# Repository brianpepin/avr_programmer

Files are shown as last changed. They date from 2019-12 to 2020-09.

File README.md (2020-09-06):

# AVR Programmer
Eagle files and gerbers for a programmer designed for Microchip's series of AVR microcontrollers. There is also a KiCad variant in the kicad directory, but I haven't tried it yet.  It was ported from Eagle and I re-routed the board.

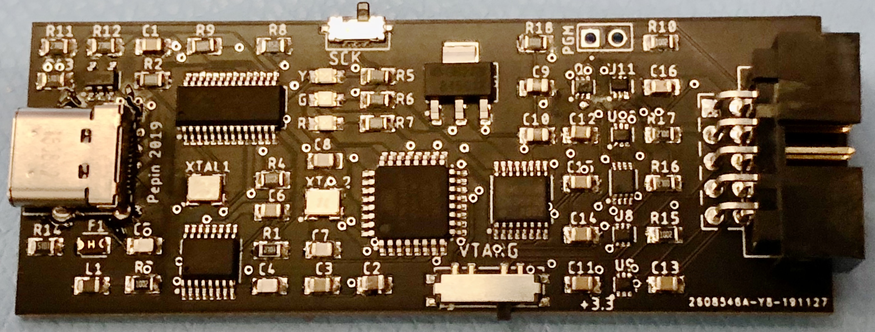
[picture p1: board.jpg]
Board Image


## Overview
Microchip's series of AVR chips are simple 8 bit microcontrollers often used in Arduino boards. This programmer board can be used to program fuses and flash for bare AVR chips.

## Features

* Compatible with USBASP firmware and features, including slow clock.
* Selectable target voltage of 3.3v, 5v, or target provided (1.8v - 5.5v).
* Built-in serial to USB converter.
* Board can remain connected to target after programming.
* USB-C interface to PC with full ESD and overload protection.

## Design

This board is based on the hardware design for [USBASP](https://www.fischl.de/usbasp/) and is 100% compatible wth the USBASP firmware. I designed it to support different target voltages (namely 3.3v) and wanted built-in serial IO so I could connect a single connector to boards I design.

The board shows up as two USB devices: a FTDI serial port and a USBASP programmer.  There is an on-board USB hub that exposes both devices.  Target voltage is selectable through the VTARG switch and has three values:

1. 5V (left): Provide 5 volts as power and logic levels to the target board.
1. Float (middle): Adapt to whatever voltage the target board is using.
1. 3.3V (right): Provide 3.3 volts as power and logic levels to the target board.

If your board provides voltage of its own make sure you keep VTARG in the middle position.

The different voltage levels are shifted through an array of level shifters.  This circuit will change direction of the signals if PGM is bridged, which allows for initial programming of the board. All connections other than TXD and RXD also go to a high-impedance state whenever the red programming light is off (I reuse that signal line so I don't need any modifications to the USBASP firmware). Signal direction and tri-state is controlled by discrete logic, again so no USBASP mods are needed.  The level shifters I'm using go to high-impedance state when VCCA or VCCB is grounded.  This is handled by a push-pull pair of mosfets driven by discrete logic.

## Programming

Once the board is complete it must be flashed with the USBASP code. You need another working programmer for this.

1. Bridge the PGM pins on the board and set VTARG to either 5v or 3.3v depending on the output voltage of your existing programmer.
1. Connect your existing programmer's connector to the board.
1. Set your programmer to use a slow clock.
1. Run 'make Makefile88 fuses' from the USBASP project.
1. You can now turn off the slow clock feature of your programmer.
1. Run 'make Makefile88" to flash the firmware.

If successful, a green LED should be lit on the board. This LED is controlled by the USBASP firmware so it's a good indicator everything's working.  Remove the bridge to PGM and you should be good to go.

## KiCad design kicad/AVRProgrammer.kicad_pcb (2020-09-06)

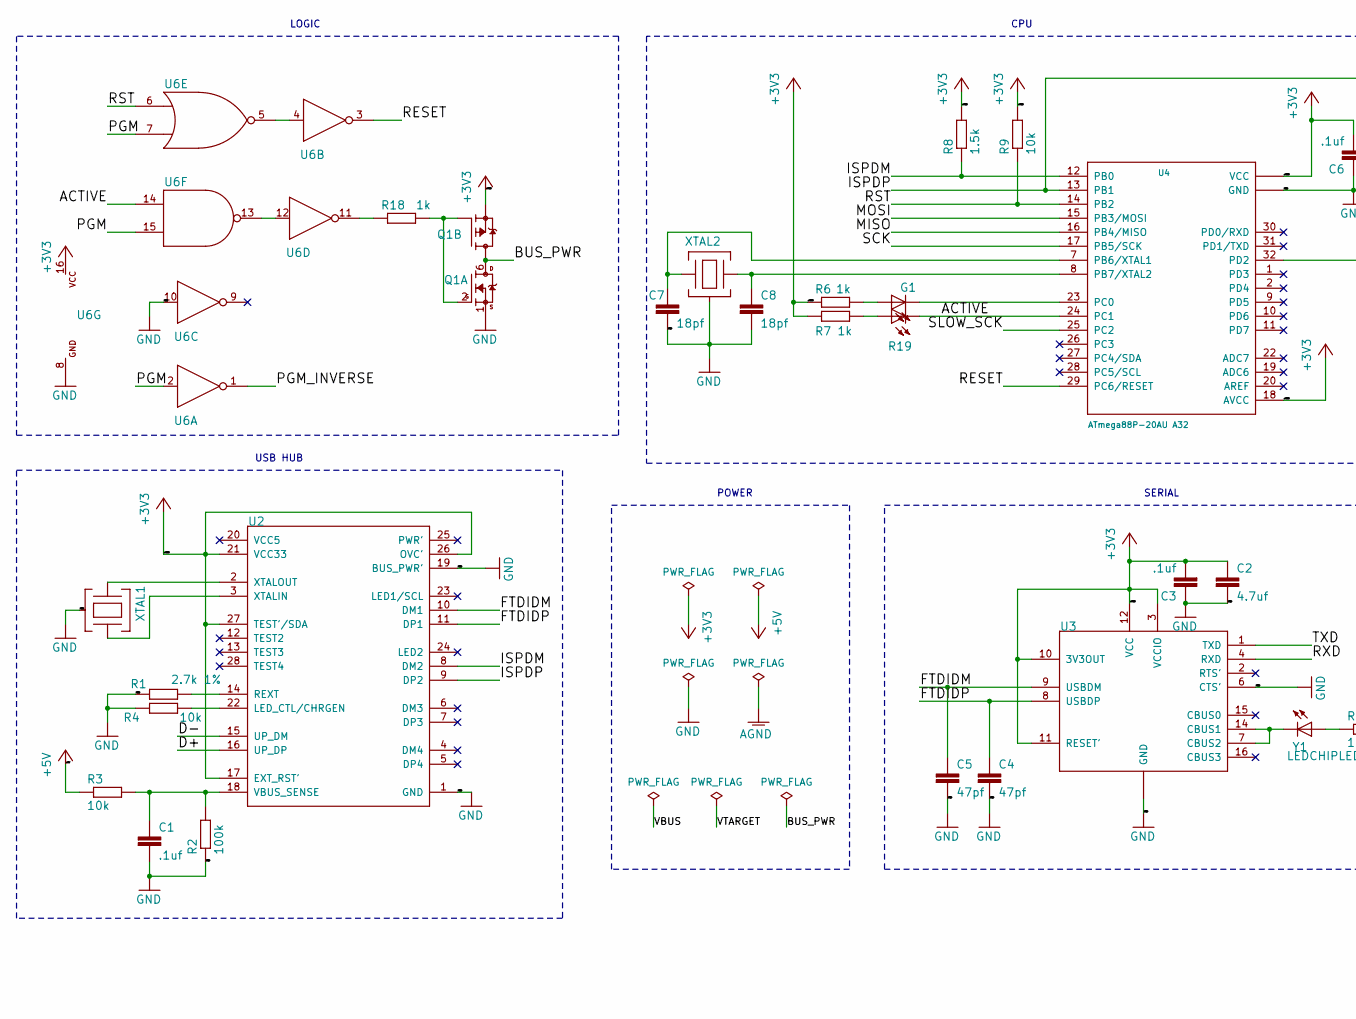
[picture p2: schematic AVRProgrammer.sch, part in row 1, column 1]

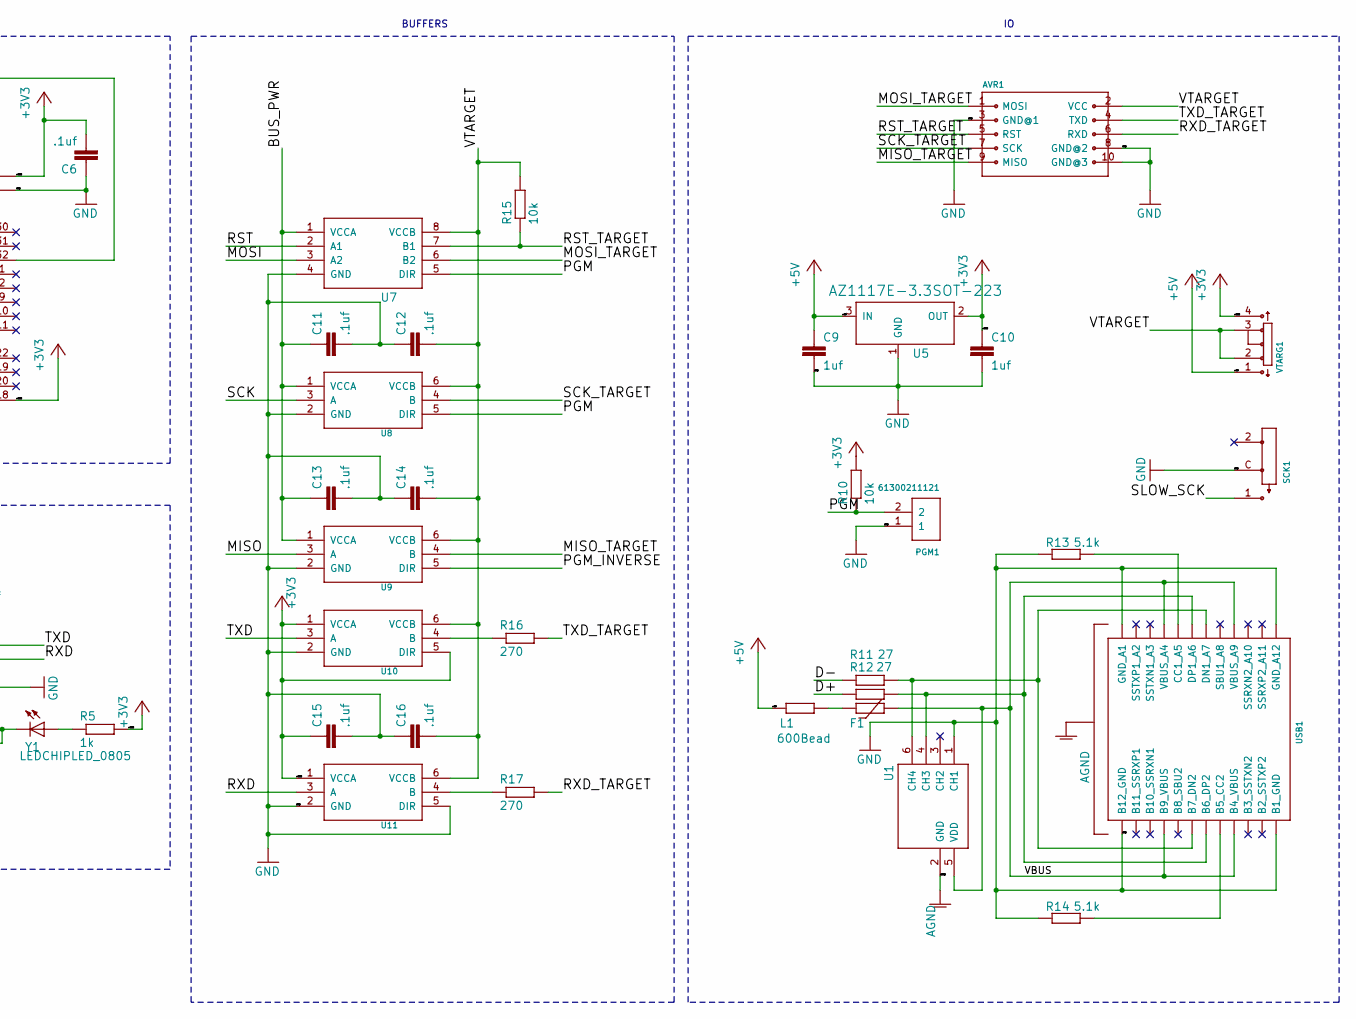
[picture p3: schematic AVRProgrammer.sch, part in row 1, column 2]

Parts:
AVR1: 10PIN_ISP10PIN_ISP_RT; 10PIN_ISP_RT
C1, C3, C6, C11, C12, C13, C14, C15, C16: .1uf; C0805
C2: 4.7uf; C0805
C4, C5: 47pf; C0805
C7, C8: 18pf; C0805
C9, C10: 1uf; C0805
F1: MF-PSHT035KX-2; FUSC2113X120N
G1: SM0805GCL; CHIPLED_0805
L1: 600Bead; M0805
PGM1: 61300211121
Q1: SI1016CX-T1-GE3SOT-563F; SOTFL50P160X60-6N
R1: 2.7k 1%; M0805
R2: 100k; M0805
R3, R4, R9: 10k; M0805
R5, R6, R7, R18: 1k; M0805
R8: 1.5k; M0805
R10, R15: 10k; R0805
R11, R12: 27; M0805
R13, R14: 5.1k; M0805
R16, R17: 270; R0805
R19: SM0805HCL; CHIPLED_0805
SCK1: SPDT_SWITCH; SSAJ110100
U1: D5V0F4U6SO; SOT95P280X145-6
U2: XR22404SSOP28; SOP63P599X173-28
U3: FT230XSSOP16; SOP63P599X175-16
U4: ATmega88P-20AU A32; QFP80P887X887X120-32
U5: AZ1117E-3.3SOT-223; SOT230P700X180-4
U6: CD4572UB; SOP65P640X110-16N
U7: SN74LVC2T45-Q1VSSOP-8; SOP50P310X90-8N
U8, U9, U10, U11: SN74LVC1T45DRL; SOTFL50P160X60-6N
USB1: USBC_FEMALEUJ31-CH-G2-SMT-TR; USBC_UJ31-CH-G2-SMT-TR
VTARG1: SP3T_SWITCH; EG1315AA
XTAL1, XTAL2: XTAL_ABM8AIG; XTAL_SMT_3.2X2.5
Y1: LEDCHIPLED_0805; CHIPLED_0805

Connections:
+3V3: C2.1, C3.2, C6.2, C10.1, C15.1, Q1.4 (S), R5.2, R6.1, R7.1, R8.2, R9.2, R10.2, U2.17 (EXT_RST'), U2.21 (VCC33), U2.26 (OVC'), U2.27 (TEST'/SDA), U3.3 (VCCIO), U3.10 (3V3OUT), U3.11 (RESET'), U3.12 (VCC), U4.4 (VCC), U4.6 (VCC), U4.18 (AVCC), U5.2 (OUT), U6.16 (VCC), U10.1 (VCCA), U10.5 (DIR), U11.1 (VCCA), VTARG1.4
+5V: C9.1, L1.1, R3.1, U5.3 (IN), VTARG1.1
/ACTIVE: R19.C, U4.24 (PC1), U6.14 (I0)
/BUS_PWR: C11.1, C13.1, Q1.3 (D), Q1.6 (D), U7.1 (VCCA), U8.1 (VCCA), U9.1 (VCCA)
/D+: R12.1, U2.16 (UP_DP)
/D-: R11.1, U2.15 (UP_DM)
/FTDIDM: C5.1, U2.10 (DM1), U3.9 (USBDM)
/FTDIDP: C4.1, U2.11 (DP1), U3.8 (USBDP)
/ISPDM: R8.1, U2.8 (DM2), U4.12 (PB0)
/ISPDP: U2.9 (DP2), U4.13 (PB1), U4.32 (PD2)
/MISO: U4.16 (PB4/MISO), U9.3 (A)
/MISO_TARGET: AVR1.9 (MISO), U9.4 (B)
/MOSI: U4.15 (PB3/MOSI), U7.3 (A2)
/MOSI_TARGET: AVR1.1 (MOSI), U7.6 (B2)
/PGM: PGM1.2, R10.1, U6.2 (A), U6.7 (I1), U6.15 (I1), U7.5 (DIR), U8.5 (DIR)
/PGM_INVERSE: U6.1 (Y), U9.5 (DIR)
/RESET: U4.29 (PC6/RESET), U6.3 (Y)
/RST: R9.1, U4.14 (PB2), U6.6 (I0), U7.2 (A1)
/RST_TARGET: AVR1.5 (RST), R15.1, U7.7 (B1)
/RXD: U3.4 (RXD), U11.3 (A)
/RXD_TARGET: AVR1.6 (RXD), R17.2
/SCK: U4.17 (PB5/SCK), U8.3 (A)
/SCK_TARGET: AVR1.7 (SCK), U8.4 (B)
/SLOW_SCK: SCK1.1, U4.25 (PC2)
/TXD: U3.1 (TXD), U10.3 (A)
/TXD_TARGET: AVR1.4 (TXD), R16.2
/VBUS: F1.2, U1.5 (VDD), USB1.A4 (VBUS_A4), USB1.A9 (VBUS_A9), USB1.B4 (B4_VBUS), USB1.B9 (B9_VBUS)
/VTARGET: AVR1.2 (VCC), C12.2, C14.2, C16.2, R15.2, U7.8 (VCCB), U8.6 (VCCB), U9.6 (VCCB), U10.6 (VCCB), U11.6 (VCCB), VTARG1.2, VTARG1.3 (C)
AGND: U1.2 (GND), USB1.SHD$1 (SHLD), USB1.SHD$2 (SHLD), USB1.SHD$3 (SHLD), USB1.SHD$4 (SHLD)
GND: AVR1.3 (GND@1), AVR1.8 (GND@2), AVR1.10 (GND@3), C1.2, C2.2, C3.1, C4.2, C5.2, C6.1, C7.2, C8.2, C9.2, C10.2, C11.2, C12.1, C13.2, C14.1, C15.2, C16.1, PGM1.1, Q1.1 (S), R1.1, R2.1, R4.1, R13.1, R14.1, SCK1.C, U1.1 (CH1), U2.1 (GND), U2.19 (BUS_PWR'), U3.5 (GND), U3.6 (CTS'), U3.13 (GND), U4.3 (GND), U4.5 (GND), U4.21 (GND), U5.1 (GND), U6.8 (GND), U6.10 (A), U7.4 (GND), U8.2 (GND), U9.2 (GND), U10.2 (GND), U11.2 (GND), U11.5 (DIR), USB1.A1 (GND_A1), USB1.A12 (GND_A12), USB1.B1 (B1_GND), USB1.B12 (B12_GND), XTAL1.2 (CASE), XTAL1.4 (CASE), XTAL2.2 (CASE), XTAL2.4 (CASE)
unnamed: C1.1, R2.2, R3.2, U2.18 (VBUS_SENSE)
unnamed: C7.1, U4.7 (PB6/XTAL1), XTAL2.1
unnamed: C8.1, U4.8 (PB7/XTAL2), XTAL2.3
unnamed: F1.1, L1.2
unnamed: G1.A, R6.2
unnamed: G1.C, U4.23 (PC0)
unnamed: Q1.2 (G), Q1.5 (G), R18.2
unnamed: R1.2, U2.14 (REXT)
unnamed: R4.2, U2.22 (LED_CTL/CHRGEN)
unnamed: R5.1, Y1.A
unnamed: R11.2, U1.6 (CH4), USB1.A7 (DN1_A7), USB1.B7 (B7_DN2)
unnamed: R12.2, U1.4 (CH3), USB1.A6 (DP1_A6), USB1.B6 (B6_DP2)
unnamed: R13.2, USB1.A5 (CC1_A5)
unnamed: R14.2, USB1.B5 (B5_CC2)
unnamed: R16.1, U10.4 (B)
unnamed: R17.1, U11.4 (B)
unnamed: R18.1, U6.11 (Y)
unnamed: R7.2, R19.A
unnamed: U2.2 (XTALOUT), XTAL1.1
unnamed: U2.3 (XTALIN), XTAL1.3
unnamed: U3.7 (CBUS2), U3.14 (CBUS1), Y1.C
unnamed: U6.4 (A), U6.5 (O)
unnamed: U6.12 (A), U6.13 (O)

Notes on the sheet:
BUFFERS
CPU
SERIAL
USB HUB
LOGIC
POWER

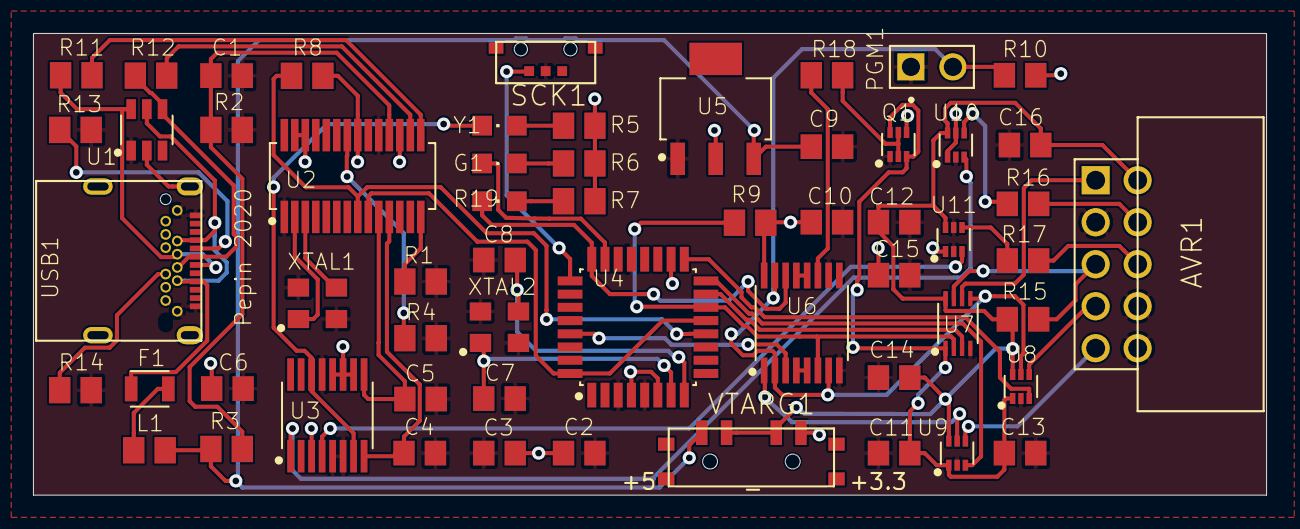
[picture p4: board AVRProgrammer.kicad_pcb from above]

Board: 2 copper layers, 74.6 x 27.9 mm, 58 parts (0 on the bottom side), 53 nets.

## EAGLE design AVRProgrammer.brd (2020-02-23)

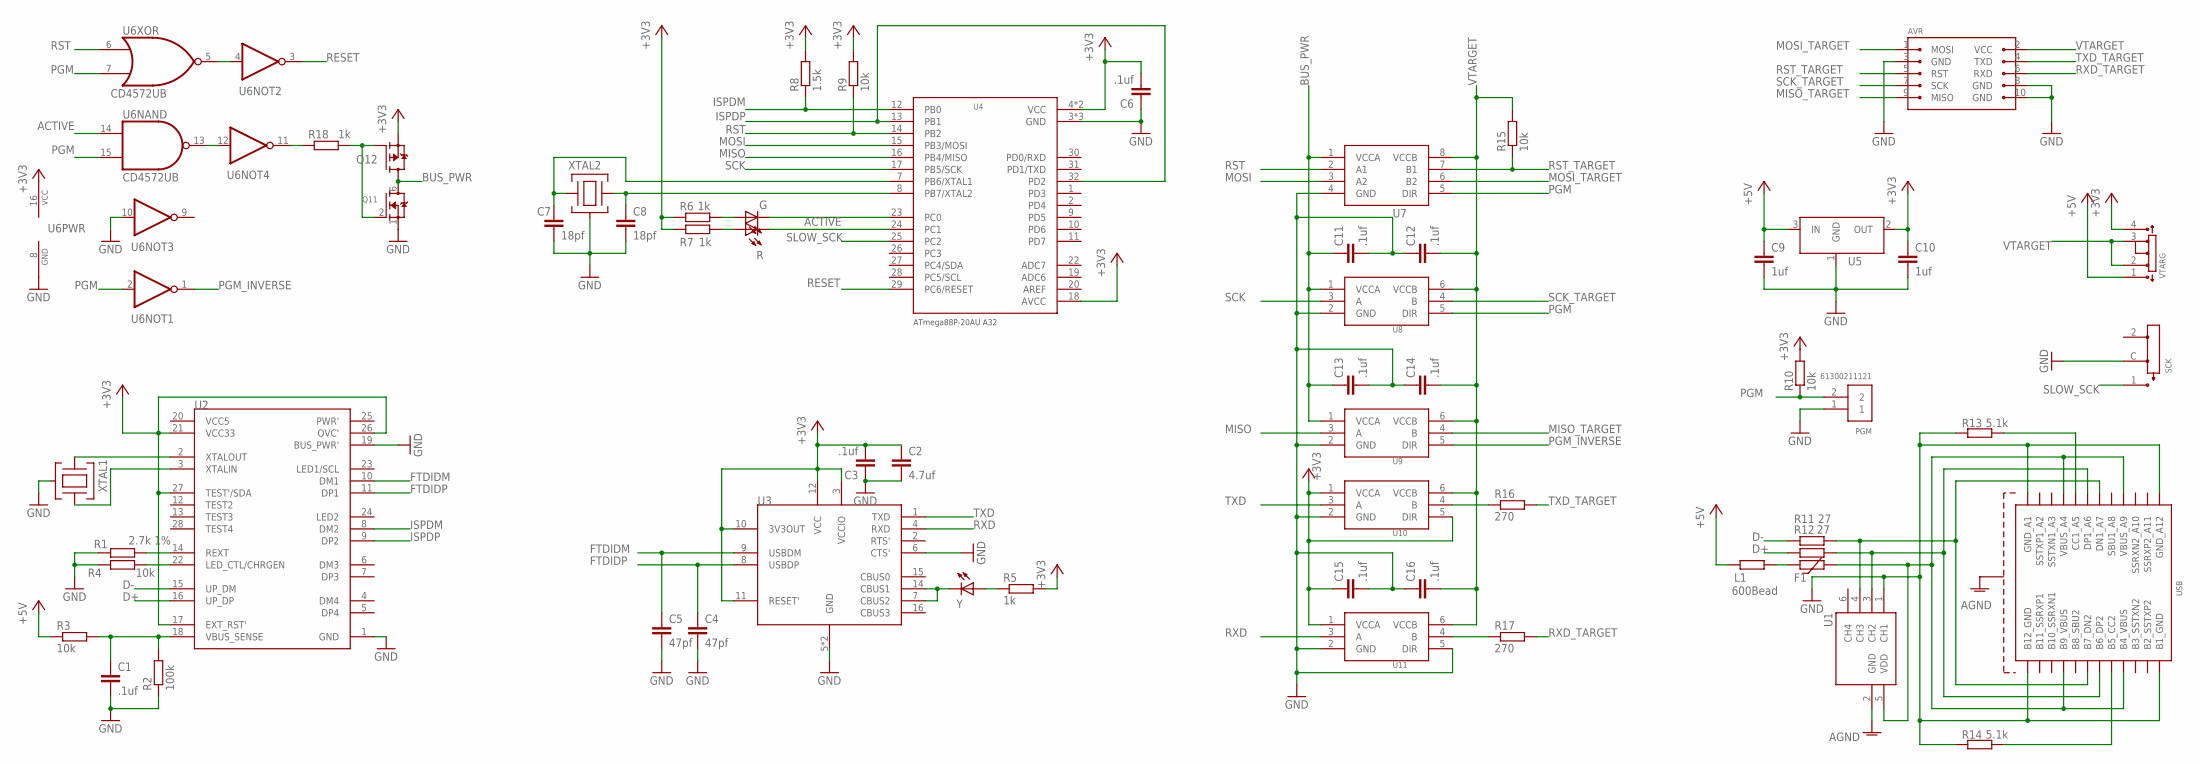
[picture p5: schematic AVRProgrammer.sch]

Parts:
AVR: 10PIN_ISP10PIN_ISP_RT; 10PIN_ISP_RT
C1, C3, C6, C11, C12, C13, C14, C15, C16: .1uf; C0805
C2: 4.7uf; C0805
C4, C5: 47pf; C0805
C7, C8: 18pf; C0805
C9, C10: 1uf; C0805
F1: MF-PSHT035KX-2; FUSC2113X120N
G: SM0805GCL; CHIPLED_0805
L1: 600Bead; M0805
PGM: 61300211121
Q1: SI1016CX-T1-GE3SOT-563F; SOTFL50P160X60-6N
R: SM0805HCL; CHIPLED_0805
R1: 2.7k 1%; M0805
R2: 100k; M0805
R3, R4, R9: 10k; M0805
R5, R6, R7, R18: 1k; M0805
R8: 1.5k; M0805
R10, R15: 10k; R0805
R11, R12: 27; M0805
R13, R14: 5.1k; M0805
R16, R17: 270; R0805
SCK: SPDT_SWITCH; SSAJ110100
U1: D5V0F4U6SO; SOT95P280X145-6
U2: XR22404SSOP28; SOP63P599X173-28
U3: FT230XSSOP16; SOP63P599X175-16
U4: ATmega88P-20AU A32; QFP80P887X887X120-32
U5: AZ1117E-3.3SOT-223; SOT230P700X180-4
U6: CD4572UB; SOP65P640X110-16N
U7: SN74LVC2T45-Q1VSSOP-8; SOP50P310X90-8N
U8, U9, U10, U11: SN74LVC1T45DRL; SOTFL50P160X60-6N
USB: USBC_FEMALEUJ31-CH-G2-SMT-TR; USBC_UJ31-CH-G2-SMT-TR
VTARG: SP3T_SWITCH; EG1315AA
XTAL1, XTAL2: XTAL_ABM8AIG; XTAL_SMT_3.2X2.5
Y: LEDCHIPLED_0805; CHIPLED_0805

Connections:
+3V3: C2.1, C3.2, C6.2, C10.1, C15.1, Q1.4 (S), R5.2, R6.1, R7.1, R8.2, R9.2, R10.2, U2.17 (EXT_RST'), U2.21 (VCC33), U2.26 (OVC'), U2.27 (TEST'/SDA), U3.3 (VCCIO), U3.10 (3V3OUT), U3.11 (RESET'), U3.12 (VCC), U4.4 (VCC), U4.6 (VCC), U4.18 (AVCC), U5.2 (OUT), U6.16 (VCC), U10.1 (VCCA), U10.5 (DIR), U11.1 (VCCA), VTARG.4
+5V: C9.1, L1.1, R3.1, U5.3 (IN), VTARG.1
ACTIVE: R.C, U4.24 (PC1), U6.14 (I0)
AGND: U1.2 (GND), USB.SHD$1 (SHLD), USB.SHD$2 (SHLD), USB.SHD$3 (SHLD), USB.SHD$4 (SHLD)
BUS_PWR: C11.1, C13.1, Q1.3 (D), Q1.6 (D), U7.1 (VCCA), U8.1 (VCCA), U9.1 (VCCA)
D+: R12.1, U2.16 (UP_DP)
D-: R11.1, U2.15 (UP_DM)
FTDIDM: C5.1, U2.10 (DM1), U3.9 (USBDM)
FTDIDP: C4.1, U2.11 (DP1), U3.8 (USBDP)
GND: AVR.3 (GND), AVR.8 (GND), AVR.10 (GND), C1.2, C2.2, C3.1, C4.2, C5.2, C6.1, C7.2, C8.2, C9.2, C10.2, C11.2, C12.1, C13.2, C14.1, C15.2, C16.1, PGM.1, Q1.1 (S), R1.1, R2.1, R4.1, R13.1, R14.1, SCK.C, U1.1 (CH1), U2.1 (GND), U2.19 (BUS_PWR'), U3.5 (GND), U3.6 (CTS'), U3.13 (GND), U4.3 (GND), U4.5 (GND), U4.21 (GND), U5.1 (GND), U6.8 (GND), U6.10 (A), U7.4 (GND), U8.2 (GND), U9.2 (GND), U10.2 (GND), U11.2 (GND), U11.5 (DIR), USB.A1 (GND_A1), USB.A12 (GND_A12), USB.B1 (B1_GND), USB.B12 (B12_GND), XTAL1.2 (CASE), XTAL1.4 (CASE), XTAL2.2 (CASE), XTAL2.4 (CASE)
ISPDM: R8.1, U2.8 (DM2), U4.12 (PB0)
ISPDP: U2.9 (DP2), U4.13 (PB1), U4.32 (PD2)
MISO: U4.16 (PB4/MISO), U9.3 (A)
MISO_TARGET: AVR.9 (MISO), U9.4 (B)
MOSI: U4.15 (PB3/MOSI), U7.3 (A2)
MOSI_TARGET: AVR.1 (MOSI), U7.6 (B2)
unnamed: Q1.2 (G), Q1.5 (G), R18.2
unnamed: C1.1, R2.2, R3.2, U2.18 (VBUS_SENSE)
unnamed: U2.2 (XTALOUT), XTAL1.1
unnamed: R1.2, U2.14 (REXT)
unnamed: U2.3 (XTALIN), XTAL1.3
unnamed: R4.2, U2.22 (LED_CTL/CHRGEN)
unnamed: R13.2, USB.A5 (CC1_A5)
unnamed: U3.7 (CBUS2), U3.14 (CBUS1), Y.C
unnamed: R5.1, Y.A
unnamed: R14.2, USB.B5 (B5_CC2)
unnamed: R18.1, U6.11 (Y)
unnamed: C7.1, U4.7 (PB6/XTAL1), XTAL2.1
unnamed: C8.1, U4.8 (PB7/XTAL2), XTAL2.3
unnamed: F1.1, L1.2
unnamed: G.A, R6.2
unnamed: R.A, R7.2
unnamed: G.C, U4.23 (PC0)
unnamed: U6.12 (A), U6.13 (O)
unnamed: U6.4 (A), U6.5 (O)
unnamed: R11.2, U1.4 (CH3), USB.A7 (DN1_A7), USB.B7 (B7_DN2)
unnamed: R12.2, U1.3 (CH2), USB.A6 (DP1_A6), USB.B6 (B6_DP2)
unnamed: F1.2, U1.5 (VDD), USB.A4 (VBUS_A4), USB.A9 (VBUS_A9), USB.B4 (B4_VBUS), USB.B9 (B9_VBUS)
unnamed: R16.1, U10.4 (B)
unnamed: R17.1, U11.4 (B)
PGM: PGM.2, R10.1, U6.2 (A), U6.7 (I1), U6.15 (I1), U7.5 (DIR), U8.5 (DIR)
PGM_INVERSE: U6.1 (Y), U9.5 (DIR)
RESET: U4.29 (PC6/RESET), U6.3 (Y)
RST: R9.1, U4.14 (PB2), U6.6 (I0), U7.2 (A1)
RST_TARGET: AVR.5 (RST), R15.1, U7.7 (B1)
RXD: U3.4 (RXD), U11.3 (A)
RXD_TARGET: AVR.6 (RXD), R17.2
SCK: U4.17 (PB5/SCK), U8.3 (A)
SCK_TARGET: AVR.7 (SCK), U8.4 (B)
SLOW_SCK: SCK.1, U4.25 (PC2)
TXD: U3.1 (TXD), U10.3 (A)
TXD_TARGET: AVR.4 (TXD), R16.2
VCC5: U2.20 (VCC5)
VTARGET: AVR.2 (VCC), C12.2, C14.2, C16.2, R15.2, U7.8 (VCCB), U8.6 (VCCB), U9.6 (VCCB), U10.6 (VCCB), U11.6 (VCCB), VTARG.2, VTARG.3 (C)

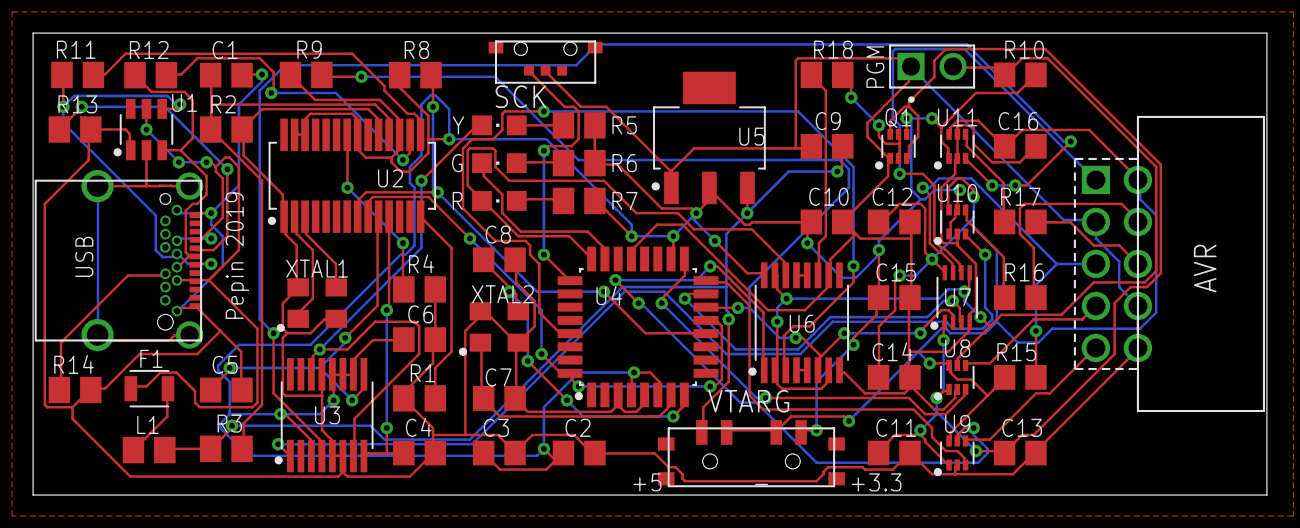
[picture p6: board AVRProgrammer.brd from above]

Board: 2 copper layers, 74.6 x 27.9 mm, 58 parts (0 on the bottom side), 53 nets.

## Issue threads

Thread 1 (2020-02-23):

ESDS314 ESD Suppressor wrong choice for protecting V_BUS

brianpepin, 2020-02-23:
The ESDS314 chip is used for ESD suppression on the USB connector across all lines, including V_BUS.  However, this chip has a reverse breakdown voltage of between 4.5 - 7.5 volts.  If you get a chip on the low end of that, it will conduct and burn up as soon as you plug in the USB connector.

Closed 2020-02-23.

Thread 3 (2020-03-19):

USBasp UART

dioannidis, 2020-03-19:
Hi,

  for some time now I'm using successfully the firmware from https://github.com/akrasuski1/usbasp-uart for my USBasps.

  Is it possible to add to your firmware UART support ?

dioannidis, 2020-03-19:
I'm closing this issue because you solved the UART USBasp's problem using a USB hardware hub.

This an RTFM error from my part ... Sorry for the noise ...

Closed 2020-03-19.

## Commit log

2019-12-10 Initial populate
    [AVRProgrammer.brd, AVRProgrammer.sch]
2020-02-23 Replace incorrect USB ESD component
    [AVRProgrammer.brd, AVRProgrammer.sch]
2020-09-06 Add KiCad version
    [AVRProgrammer.kicad_pcb, AVRProgrammer.sch]
